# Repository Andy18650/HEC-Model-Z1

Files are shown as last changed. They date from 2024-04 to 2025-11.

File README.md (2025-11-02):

# HEC Model Z1
 A Z80 computer with protected mode support
This repository is currently for my own use and for the public to track the progress of the project. 
It is not meant to be used to produce a working computer befor first beta revision is announced.
Any part of this repository may change without notice.

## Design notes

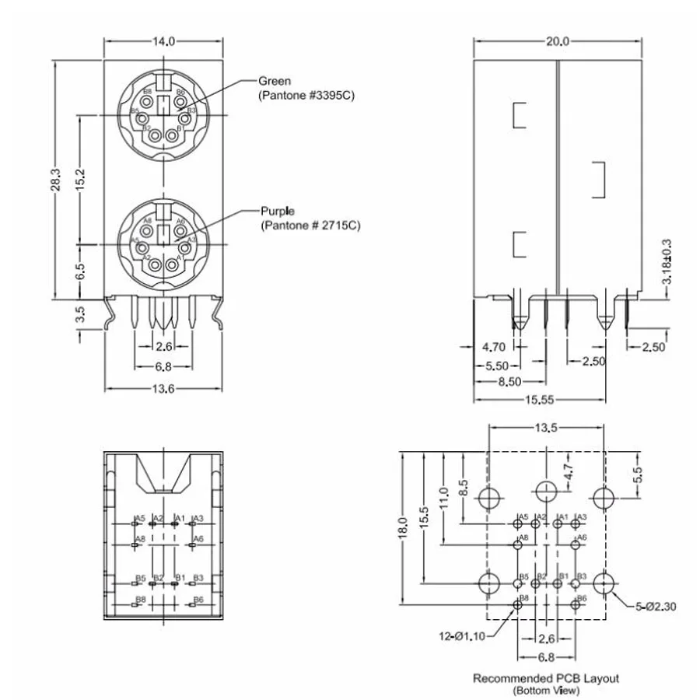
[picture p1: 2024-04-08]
mini-din-6x2.png

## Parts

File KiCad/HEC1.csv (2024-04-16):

Source: | C:\Users\11456\Desktop\Projects\HEC\HEC-Model-Z1\KiCad\HEC1.kicad_sch
Date: | 4/17/2024 1:12:58 AM
Tool: | Eeschema 7.0.2
Generator: | C:\Program Files\KiCad\7.0\bin\scripting\plugins/bom_csv_grouped_by_value.py
Component Count: | 119
Collated Components:
Item | Qty | Reference(s) | Value | LibPart | Footprint | Datasheet | DNP
1 | 1 | BUS1 | ~ | :Bus_HEC_1 | Library:Bus_HEC
2 | 1 | BUS2 | ~ | New_Library:Bus_HEC | Library:Bus_HEC
3 | 1 | BUS3 | ~ | :Bus_HEC_5Vonly_1 | Library:Bus_HEC_5Vonly
4 | 1 | BUS4 | ~ | New_Library:Bus_HEC_5Vonly | Library:Bus_HEC_5Vonly
5 | 24 | C1, C2, C3, C4, C5, C6, C7, C8, C13, C14, C15, C16, C17, C18, C19, C20, C22, C23, C24, C25, C26, C27, C28, C29 | C | Device:C | Capacitor_THT:C_Disc_D7.0mm_W2.5mm_P5.00mm | ~
6 | 3 | C9, C10, C11 | C_Polarized | Device:C_Polarized | Capacitor_THT:CP_Radial_D6.3mm_P2.50mm | ~
7 | 6 | C12, C21, C30, C33, C34, C35 | C_Polarized | Device:C_Polarized | Capacitor_THT:CP_Radial_D10.0mm_P5.00mm | ~
8 | 2 | C31, C32 | C | Device:C | Capacitor_THT:C_Disc_D3.4mm_W2.1mm_P2.50mm | ~
9 | 1 | D1 | LED | Device:LED | LED_THT:LED_D3.0mm | ~
10 | 6 | H1, H2, H3, H4, H5, H6 | MountingHole_Pad | Mechanical:MountingHole_Pad | MountingHole:MountingHole_3.2mm_M3_Pad_Via | ~
11 | 4 | H7, H8, H9, H10 | MountingHole | Mechanical:MountingHole | MountingHole:MountingHole_3.2mm_M3 | ~
12 | 1 | J1 | Barrel_Jack_Switch | Connector:Barrel_Jack_Switch | Connector_BarrelJack:BarrelJack_Kycon_KLDX-0202-xC_Horizontal | ~
13 | 1 | J2 | Conn_02x12_Odd_Even | Connector_Generic:Conn_02x12_Odd_Even | Connector_PinHeader_2.54mm:PinHeader_2x12_P2.54mm_Vertical | ~
14 | 1 | J3 | Conn_02x05_Odd_Even | Connector_Generic:Conn_02x05_Odd_Even | Connector_PinHeader_2.54mm:PinHeader_2x05_P2.54mm_Vertical | ~
15 | 1 | J4 | ~ | New_Library:double_mini-DIN_6 | Library:Connector_double_mini-DIN_6
16 | 1 | J5 | Screw_Terminal_01x02 | Connector:Screw_Terminal_01x02 | TerminalBlock_MetzConnect:TerminalBlock_MetzConnect_Type073_RT02602HBLU_1x02_P5.08mm_Horizontal | ~
17 | 1 | J6 | DE9_Plug_MountingHoles | Connector:DE9_Plug_MountingHoles | Connector_Dsub:DSUB-9_Male_Horizontal_P2.77x2.84mm_EdgePinOffset4.94mm_Housed_MountingHolesOffset7.48mm | ~
18 | 1 | J7 | AudioJack3 | Connector_Audio:AudioJack3 | Connector_Audio:Jack_3.5mm_CUI_SJ1-3533NG_Horizontal | ~
19 | 1 | J8 | NES_Port_Male | New_Library:NES_Port_Male | Library:NES_Port_Male_Horizontal
20 | 1 | J9 | Conn_02x14_Odd_Even | Connector_Generic:Conn_02x14_Odd_Even | Connector_PinHeader_2.54mm:PinHeader_2x14_P2.54mm_Vertical | ~
21 | 1 | PS1 | ITX0512S | Converter_DCDC:ITX0512S | Converter_DCDC:Converter_DCDC_XP_POWER-ITxxxxxS_THT | https://www.xppower.com/pdfs/SF_ITX.pdf
22 | 4 | R1, R2, R3, R4 | R | Device:R | Resistor_THT:R_Axial_DIN0207_L6.3mm_D2.5mm_P7.62mm_Horizontal | ~
23 | 2 | RN1, RN6 | R_Network08 | Device:R_Network08 | Resistor_THT:R_Array_SIP9 | http://www.vishay.com/docs/31509/csc.pdf
24 | 2 | RN2, RN7 | R_Network04 | Device:R_Network04 | Resistor_THT:R_Array_SIP5 | http://www.vishay.com/docs/31509/csc.pdf
25 | 2 | RN3, RN4 | R_Pack07 | Device:R_Pack07 | Package_DIP:DIP-14_W7.62mm | ~
26 | 1 | RN5 | R_Network07 | Device:R_Network07 | Resistor_THT:R_Array_SIP8 | http://www.vishay.com/docs/31509/csc.pdf
27 | 1 | SW1 | SW_DIP_x04 | Switch:SW_DIP_x04 | Button_Switch_THT:SW_DIP_SPSTx04_Slide_9.78x12.34mm_W7.62mm_P2.54mm | ~
28 | 1 | SW2 | SW_Push | Switch:SW_Push | Button_Switch_THT:SW_PUSH_6mm | ~
29 | 1 | U1 | Z80CPU | CPU:Z80CPU | Library:DIP-40_W15.24mm_Socket_ThinPads | www.zilog.com/manage_directlink.php?filepath=docs/z80/um0080
30 | 2 | U2, U3 | AS6C4008-55PCN | Memory_RAM:AS6C4008-55PCN | Library:DIP-32_W15.24mm_Socket_ThinPads | https://www.alliancememory.com/wp-content/uploads/pdf/AS6C4008.pdf
31 | 2 | U4, U5 | CY7C199 | Memory_RAM:CY7C199 | Library:DIP-28_W7.62mm_Socket_ThinPads
32 | 3 | U6, U8, U18 | 74LS138 | 74xx:74LS138 | Library:DIP-16_W7.62mm_Socket_ThinPads | http://www.ti.com/lit/gpn/sn74LS138
33 | 1 | U7 | 28C256 | Memory_EEPROM:28C256 | Library:DIP-28_W15.24mm_Socket_ThinPads | http://ww1.microchip.com/downloads/en/DeviceDoc/doc0006.pdf
34 | 4 | U9, U20, U21, U36 | 74LS574 | 74xx:74LS574 | Library:DIP-20_W7.62mm_Socket_ThinPads | http://www.ti.com/lit/gpn/sn74LS574
35 | 5 | U10, U15, U16, U31, U37 | 74LS32 | 74xx:74LS32 | Library:DIP-14_W7.62mm_Socket_ThinPads | http://www.ti.com/lit/gpn/sn74LS32
36 | 1 | U11 | 74LS00 | 74xx:74LS00 | Library:DIP-14_W7.62mm_Socket_ThinPads | http://www.ti.com/lit/gpn/sn74ls00
37 | 1 | U12 | 74LS04 | 74xx:74LS04 | Library:DIP-14_W7.62mm_Socket_ThinPads | http://www.ti.com/lit/gpn/sn74LS04
38 | 2 | U13, U14 | 74LS245 | 74xx:74LS245 | Library:DIP-20_W7.62mm_Socket_ThinPads | http://www.ti.com/lit/gpn/sn74LS245
39 | 2 | U17, U33 | 74LS20 | 74xx:74LS20 | Library:DIP-14_W7.62mm_Socket_ThinPads | http://www.ti.com/lit/gpn/sn74LS20
40 | 2 | U19, U28 | 74LS30 | 74xx:74LS30 | Library:DIP-14_W7.62mm_Socket_ThinPads | http://www.ti.com/lit/gpn/sn74LS30
41 | 2 | U22, U41 | 74LS02 | 74xx:74LS02 | Library:DIP-14_W7.62mm_Socket_ThinPads | http://www.ti.com/lit/gpn/sn74ls02
42 | 5 | U23, U24, U27, U29, U30 | 74LS74 | 74xx:74LS74 | Library:DIP-14_W7.62mm_Socket_ThinPads | 74xx/74hc_hct74.pdf
43 | 3 | U25, U26, U44 | 74LS541 | 74xx:74LS541 | Library:DIP-20_W7.62mm_Socket_ThinPads | http://www.ti.com/lit/gpn/sn74LS541
44 | 1 | U32 | LM79M05_TO220 | Regulator_Linear:LM79M05_TO220 | Package_TO_SOT_THT:TO-220-3_Vertical | https://www.onsemi.com/pub/Collateral/MC79M00-D.PDF
45 | 1 | U34 | 74LS393 | 74xx:74LS393 | Library:DIP-14_W7.62mm_Socket_ThinPads | 74xx\74LS393.pdf
46 | 1 | U35 | 74LS08 | 74xx:74LS08 | Library:DIP-14_W7.62mm_Socket_ThinPads | http://www.ti.com/lit/gpn/sn74LS08
47 | 2 | U38, U39 | 74LS47 | 74xx:74LS47 | Library:DIP-16_W7.62mm_Socket_ThinPads | http://www.ti.com/lit/gpn/sn74LS47
48 | 1 | U40 | DA04-11EWA | Display_Character:DA04-11EWA | Display_7Segment:DA04-11SURKWA | http://www.kingbrightusa.com/images/catalog/SPEC/DA04-11EWA.pdf
49 | 1 | U42 | 74LS06 | 74xx:74LS06 | Library:DIP-14_W7.62mm_Socket_ThinPads | http://www.ti.com/lit/gpn/sn74LS06
50 | 1 | U43 | ~ | New_Library:HT6542B | Library:DIP-40_W15.24mm_Socket_ThinPads
51 | 1 | X1 | CXO_DIP8 | Oscillator:CXO_DIP8 | Oscillator:Oscillator_DIP-8 | http://cdn-reichelt.de/documents/datenblatt/B400/OSZI.pdf
52 | 1 | Y1 | Crystal | Device:Crystal | Crystal:Crystal_HC18-U_Vertical | ~

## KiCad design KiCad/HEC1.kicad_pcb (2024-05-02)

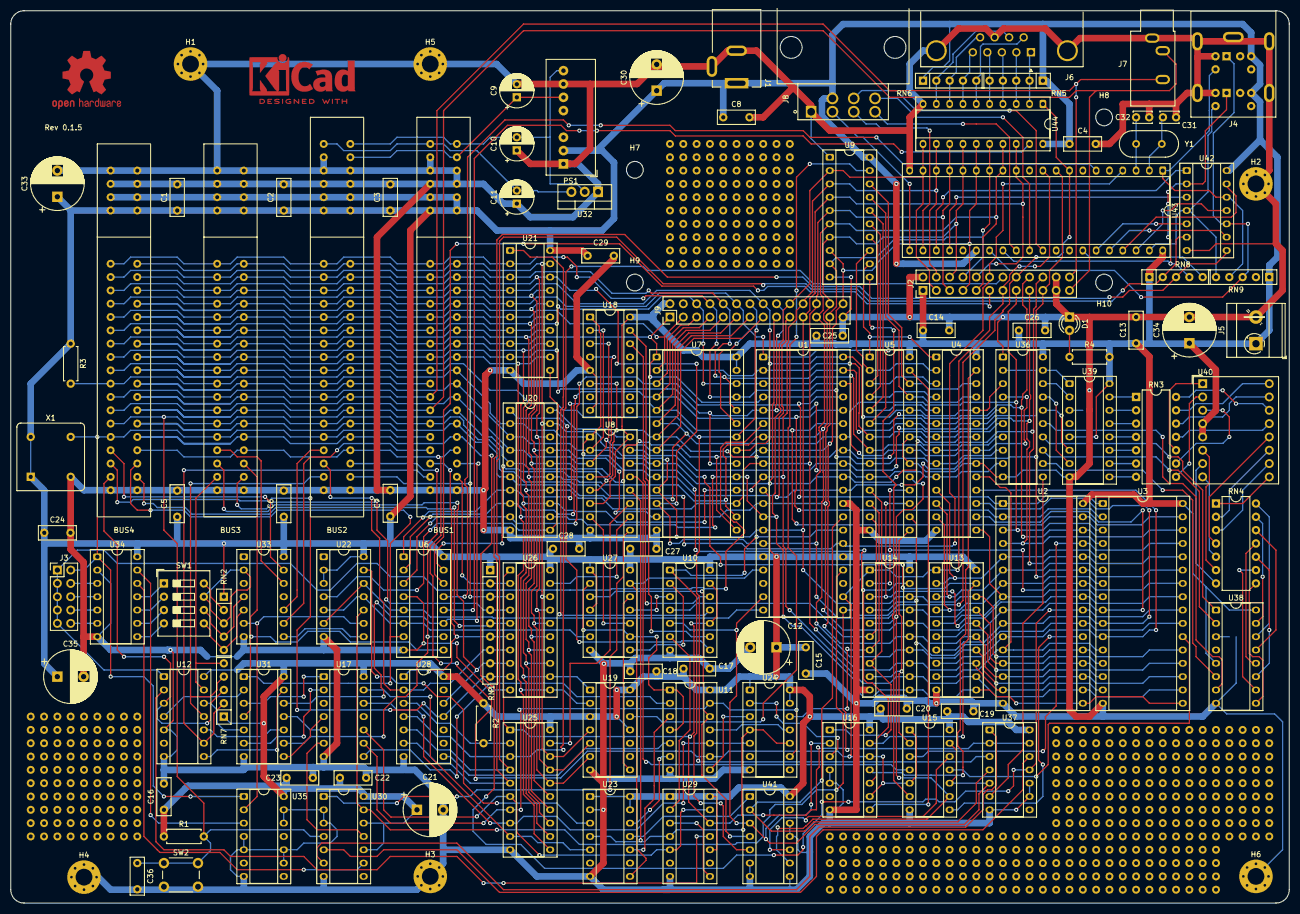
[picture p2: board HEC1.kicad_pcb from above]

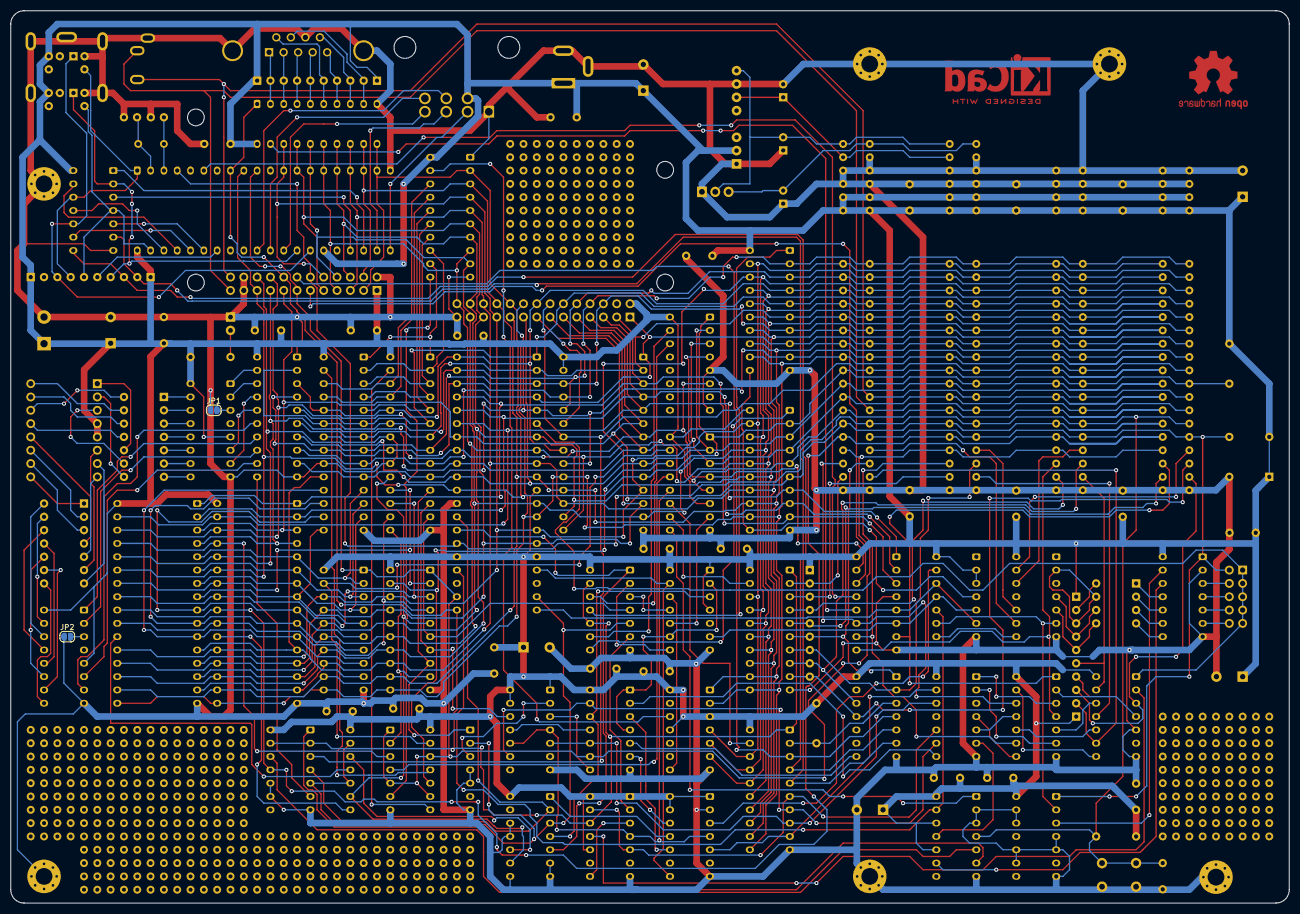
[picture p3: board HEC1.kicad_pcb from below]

Board: 2 copper layers, 243.8 x 170.2 mm, 124 parts (2 on the bottom side), 232 nets.

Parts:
BUS1, BUS2: Bus_HEC
BUS3, BUS4: Bus_HEC_5Vonly
C1, C2, C3, C4, C5, C6, C7, C8, C13, C14, C15, C16, C17, C18, C19, C20, C22, C23, C24, C25, C26, C27, C28, C29, C36: C; C_Disc_D7.0mm_W2.5mm_P5.00mm
C9, C10, C11: C_Polarized; CP_Radial_D6.3mm_P2.50mm
C12, C21, C30, C33, C34, C35: C_Polarized; CP_Radial_D10.0mm_P5.00mm
C31, C32: C; C_Disc_D3.4mm_W2.1mm_P2.50mm
D1: LED; LED_D3.0mm
H1, H2, H3, H4, H5, H6: MountingHole_Pad; MountingHole_3.2mm_M3_Pad_Via
H7, H8, H9, H10: MountingHole; MountingHole_3.2mm_M3
J1: Barrel_Jack_Switch; BarrelJack_Kycon_KLDX-0202-xC_Horizontal
J2: Conn_02x12_Odd_Even; PinHeader_2x12_P2.54mm_Vertical
J3: Conn_02x05_Odd_Even; PinHeader_2x05_P2.54mm_Vertical
J4: Connector_double_mini-DIN_6
J5: Screw_Terminal_01x02; TerminalBlock_MetzConnect_Type073_RT02602HBLU_1x02_P5.08mm_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
J6: DE9_Plug_MountingHoles; DSUB-9_Male_Horizontal_P2.77x2.84mm_EdgePinOffset4.94mm_Hou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
J7: AudioJack3; Jack_3.5mm_CUI_SJ1-3533NG_Horizontal
J8: NES_Port_Male; NES_Port_Male_Horizontal
J9: Conn_02x14_Odd_Even; PinHeader_2x14_P2.54mm_Vertical
JP1, JP2: SolderJumper_2_Open; SolderJumper-2_P1.3mm_Open_RoundedPad1.0x1.5mm
PS1: ITX0512S; Converter_DCDC_XP_POWER-ITxxxxxS_THT
R1, R2, R3, R4: R; R_Axial_DIN0207_L6.3mm_D2.5mm_P7.62mm_Horizontal
RN1: R_Network08; R_Array_SIP9
RN2, RN5, RN6, RN7, RN8, RN9: R_Network04; R_Array_SIP5
RN3, RN4: R_Pack07; DIP-14_W7.62mm
SW1: SW_DIP_x04; SW_DIP_SPSTx04_Slide_9.78x12.34mm_W7.62mm_P2.54mm
SW2: SW_Push; SW_PUSH_6mm
U1: Z80CPU; DIP-40_W15.24mm_Socket_ThinPads
U2, U3: AS6C4008-55PCN; DIP-32_W15.24mm_Socket_ThinPads
U4, U5: CY7C199; DIP-28_W7.62mm_Socket_ThinPads
U6, U8, U18: 74LS138; DIP-16_W7.62mm_Socket_ThinPads
U7: 28C256; DIP-28_W15.24mm_Socket_ThinPads
U9, U20, U21, U36: 74LS574; DIP-20_W7.62mm_Socket_ThinPads
U10, U15, U16, U31, U37: 74LS32; DIP-14_W7.62mm_Socket_ThinPads
U11: 74LS00; DIP-14_W7.62mm_Socket_ThinPads
U12: 74LS04; DIP-14_W7.62mm_Socket_ThinPads
U13, U14: 74LS245; DIP-20_W7.62mm_Socket_ThinPads
U17, U33: 74LS20; DIP-14_W7.62mm_Socket_ThinPads
U19, U28: 74LS30; DIP-14_W7.62mm_Socket_ThinPads
U22, U41: 74LS02; DIP-14_W7.62mm_Socket_ThinPads
U23, U24, U27, U29, U30: 74LS74; DIP-14_W7.62mm_Socket_ThinPads
U25, U26, U44: 74LS541; DIP-20_W7.62mm_Socket_ThinPads
U32: LM79M05_TO220; TO-220-3_Vertical
U34: 74LS393; DIP-14_W7.62mm_Socket_ThinPads
U35: 74LS08; DIP-14_W7.62mm_Socket_ThinPads
U38, U39: 74LS47; DIP-16_W7.62mm_Socket_ThinPads
U40: DA04-11EWA; DA04-11SURKWA
U42: 74LS06; DIP-14_W7.62mm_Socket_ThinPads
U43: DIP-40_W15.24mm_Socket_ThinPads
X1: CXO_DIP8; Oscillator_DIP-8
Y1: Crystal; Crystal_HC18-U_Vertical

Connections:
/HEC_CPU/CLK: J3.1, J3.3, J3.5, J3.7, J3.9, U1.6 (~CLK), U12.1
/HEC_CPU/~IOPORT_H: U10.12, U18.14 (O1)
/HEC_CPU/~IOPORT_L: U10.9, U18.15 (O0)
/HEC_CPU/~IORQ: U1.20 (~IORQ), U6.5 (E2), U22.6, U22.12
/HEC_CPU/~MREQ: U1.19 (~MREQ), U10.5, U15.10, U15.13, U16.2, U37.5, U41.3
/HEC_CPU/~NMI: U1.17 (~NMI), U23.8 (~Q), U27.13 (~R)
/HEC_CPU/~RAMEN: U8.9 (O6), U30.1 (~R)
/HEC_CPU/~RD: J2.16, U1.21 (~RD), U10.10, U10.13, U25.1 (G1), U26.1 (G1), U29.12 (D), U37.2, U37.13, U43.8 (~RD), U44.1 (G1)
/HEC_CPU/~RESET: BUS1.25 (~RESET), BUS2.25 (~RESET), BUS3.25 (~RESET), BUS4.25 (~RESET), C36.1, J2.12, R1.2, SW2.1, U1.26 (~RESET), U30.4 (~S), U43.4 (~RESET)
/HEC_CPU/~RFSH: U1.28 (~RFSH), U37.4, U41.2
/HEC_CPU/~WAIT: U1.24 (~WAIT), U22.10, U30.13 (~R)
/HEC_CPU/~WR: BUS1.30 (~IOW), BUS2.30 (~IOW), BUS3.30 (~IOW), BUS4.30 (~IOW), J2.13, U1.22 (~WR), U11.9, U13.1 (A->B), U14.1 (A->B), U15.1, U15.5, U16.9, U16.12, U43.10 (~WR)
/HEC_IO/+12V: BUS1.P4 (+12V), BUS2.P4 (+12V), C9.1, PS1.6 (+Vout)
/HEC_IO/-5V: BUS1.P1 (-5V), BUS2.P1 (-5V), C11.2, U32.3 (VO)
/HEC_IO/-12V: BUS1.P2 (-12V), BUS2.P2 (-12V), C10.2, PS1.8 (-Vout), U32.2 (VI)
/HEC_IO/A0: BUS1.18 (PA0), BUS2.18 (PA0), BUS3.18 (PA0), BUS4.18 (PA0), J2.19, J9.19, U1.30 (A0), U2.27 (A8), U3.27 (A8), U7.10 (A0), U8.1 (A0), U18.1 (A0), U20.2 (D0), U43.9 (A0)
/HEC_IO/A1: BUS1.20 (PA1), BUS2.20 (PA1), BUS3.20 (PA1), BUS4.20 (PA1), J2.20, J9.17, U1.31 (A1), U2.28 (A13), U3.28 (A13), U7.9 (A1), U8.2 (A1), U18.2 (A1), U20.3 (D1)
/HEC_IO/A2: BUS1.22 (PA2), BUS2.22 (PA2), BUS3.22 (PA2), BUS4.22 (PA2), J2.17, J9.15, U1.32 (A2), U2.4 (A12), U3.4 (A12), U7.8 (A2), U8.3 (A2), U18.3 (A2), U20.4 (D2)
/HEC_IO/A3: BUS1.24 (PA3), BUS2.24 (PA3), BUS3.24 (PA3), BUS4.24 (PA3), J2.18, J9.13, U1.33 (A3), U2.30 (A17), U3.30 (A17), U7.7 (A3), U8.5 (E2), U18.6 (E3), U20.5 (D3)
/HEC_IO/A4: BUS1.26 (PA4), BUS2.26 (PA4), BUS3.26 (PA4), BUS4.26 (PA4), J2.15, J9.11, U1.34 (A4), U2.3 (A14), U3.3 (A14), U7.6 (A4), U20.6 (D4)
/HEC_IO/A5: J9.9, U1.35 (A5), U2.31 (A15), U3.31 (A15), U6.1 (A0), U7.5 (A5), U20.7 (D5)
/HEC_IO/A6: J9.7, U1.36 (A6), U2.2 (A16), U3.2 (A16), U6.2 (A1), U7.4 (A6), U20.8 (D6)
/HEC_IO/A7: J9.5, U1.37 (A7), U2.1 (A18), U3.1 (A18), U6.3 (A2), U7.3 (A7), U20.9 (D7)
/HEC_IO/A8: BUS1.1 (A0), BUS2.1 (A0), BUS3.1 (A0), BUS4.1 (A0), J9.8, U1.38 (A8), U4.21 (A0), U5.21 (A0), U7.25 (A8), U21.2 (D0), U36.4 (D2)
/HEC_IO/A9: BUS1.3 (A1), BUS2.3 (A1), BUS3.3 (A1), BUS4.3 (A1), J9.10, U1.39 (A9), U4.23 (A1), U5.23 (A1), U7.24 (A9), U21.3 (D1), U36.2 (D0)
/HEC_IO/A10: BUS1.5 (A2), BUS2.5 (A2), BUS3.5 (A2), BUS4.5 (A2), J9.16, U1.40 (A10), U4.24 (A2), U5.24 (A2), U7.21 (A10), U21.4 (D2), U36.3 (D1)
/HEC_IO/A11: BUS1.7 (A3), BUS2.7 (A3), BUS3.7 (A3), BUS4.7 (A3), J9.12, U1.1 (A11), U4.6 (A10), U5.6 (A10), U7.23 (A11), U21.5 (D3), U36.5 (D3)
/HEC_IO/A12: BUS1.9 (A4), BUS2.9 (A4), BUS3.9 (A4), BUS4.9 (A4), J9.3, U1.2 (A12), U4.7 (A11), U5.7 (A11), U7.2 (A12), U21.6 (D4), U36.6 (D4)
/HEC_IO/A13: BUS1.11 (A5), BUS2.11 (A5), BUS3.11 (A5), BUS4.11 (A5), J9.6, U1.3 (A13), U4.8 (A12), U5.8 (A12), U7.26 (A13), U21.7 (D5), U36.7 (D5)
/HEC_IO/A14: BUS1.13 (A6), BUS2.13 (A6), BUS3.13 (A6), BUS4.13 (A6), J9.1, U1.4 (A14), U4.9 (A13), U5.9 (A13), U7.1 (A14), U21.8 (D6), U36.8 (D6)
/HEC_IO/A15: BUS1.15 (A7), BUS2.15 (A7), BUS3.15 (A7), BUS4.15 (A7), J9.18, U1.5 (A15), U4.10 (A14), U5.10 (A14), U7.20 (~CS), U21.9 (D7), U36.9 (D7)
/HEC_IO/AUDIO_L: BUS1.21 (AUDIO_L), BUS2.21 (AUDIO_L), BUS3.21 (AUDIO_L), BUS4.21 (AUDIO_L), J2.24, J7.R
/HEC_IO/AUDIO_R: BUS1.23 (AUDIO_R), BUS2.23 (AUDIO_R), BUS3.23 (AUDIO_R), BUS4.23 (AUDIO_R), J2.23, J7.T
/HEC_IO/D0: BUS1.2 (D0), BUS2.2 (D0), BUS3.2 (D0), BUS4.2 (D0), J2.10, J9.21, U1.14 (D0), U2.21 (DQ7), U3.21 (DQ7), U7.11 (D0), U9.4 (D2), U13.18 (B0), U14.18 (B0), U19.4, U20.19 (Q0), U21.19 (Q0), U25.18 (Y0), U26.18 (Y0), U43.12 (D0), U44.18 (Y0)
/HEC_IO/D1: BUS1.4 (D1), BUS2.4 (D1), BUS3.4 (D1), BUS4.4 (D1), J2.9, J9.23, U1.15 (D1), U2.13 (DQ0), U3.13 (DQ0), U7.12 (D1), U9.6 (D4), U13.17 (B1), U14.17 (B1), U19.5, U20.18 (Q1), U21.18 (Q1), U25.17 (Y1), U26.17 (Y1), U43.13 (D1), U44.17 (Y1)
/HEC_IO/D2: BUS1.6 (D2), BUS2.6 (D2), BUS3.6 (D2), BUS4.6 (D2), J2.8, J9.25, U1.12 (D2), U2.20 (DQ6), U3.20 (DQ6), U7.13 (D2), U9.9 (D7), U13.16 (B2), U14.16 (B2), U19.6, U20.17 (Q2), U21.17 (Q2), U25.16 (Y2), U26.16 (Y2), U43.14 (D2), U44.16 (Y2)
/HEC_IO/D3: BUS1.8 (D3), BUS2.8 (D3), BUS3.8 (D3), BUS4.8 (D3), J2.7, J9.28, U1.8 (D3), U2.14 (DQ1), U3.14 (DQ1), U7.15 (D3), U9.8 (D6), U13.15 (B3), U14.15 (B3), U20.16 (Q3), U21.16 (Q3), U25.15 (Y3), U26.15 (Y3), U43.15 (D3), U44.15 (Y3)
/HEC_IO/D4: BUS1.10 (D4), BUS2.10 (D4), BUS3.10 (D4), BUS4.10 (D4), J2.6, J9.26, U1.7 (D4), U2.19 (DQ5), U3.19 (DQ5), U7.16 (D4), U9.7 (D5), U13.14 (B4), U14.14 (B4), U20.15 (Q4), U21.15 (Q4), U25.14 (Y4), U26.14 (Y4), U43.16 (D4), U44.14 (Y4)
/HEC_IO/D5: BUS1.12 (D5), BUS2.12 (D5), BUS3.12 (D5), BUS4.12 (D5), J2.5, J9.24, U1.9 (D5), U2.15 (DQ2), U3.15 (DQ2), U7.17 (D5), U9.5 (D3), U13.13 (B5), U14.13 (B5), U20.14 (Q5), U21.14 (Q5), U25.13 (Y5), U26.13 (Y5), U43.17 (D5), U44.13 (Y5)
/HEC_IO/D6: BUS1.14 (D6), BUS2.14 (D6), BUS3.14 (D6), BUS4.14 (D6), J2.4, J9.22, U1.10 (D6), U2.18 (DQ4), U3.18 (DQ4), U7.18 (D6), U9.3 (D1), U13.12 (B6), U14.12 (B6), U19.1, U20.13 (Q6), U21.13 (Q6), U25.12 (Y6), U26.12 (Y6), U43.18 (D6), U44.12 (Y6)
/HEC_IO/D7: BUS1.16 (D7), BUS2.16 (D7), BUS3.16 (D7), BUS4.16 (D7), J2.3, J9.20, U1.13 (D7), U2.17 (DQ3), U3.17 (DQ3), U7.19 (D7), U9.2 (D0), U13.11 (B7), U14.11 (B7), U19.2, U20.12 (Q7), U21.12 (Q7), U25.11 (Y7), U26.11 (Y7), U43.19 (D7), U44.11 (Y7)
/HEC_IO/OSC: BUS1.27 (OSC), BUS2.27 (OSC), BUS3.27 (OSC), BUS4.27 (OSC), J3.2, U34.1 (CP), U35.1, X1.5 (OUT)
/HEC_IO/~IOR: BUS1.28 (~IOR), BUS2.28 (~IOR), BUS3.28 (~IOR), BUS4.28 (~IOR), U2.24 (OE#), U3.24 (OE#), U37.11
/HEC_IO/~IO_CS0: U6.15 (O0), U8.4 (E1), U18.4 (E1)
/HEC_IO/~IO_CS1: J2.11, U6.14 (O1)
/HEC_IO/~IO_CS2: U6.13 (O2), U43.6 (~CS)
/HEC_IO/~IO_CS3: U6.12 (O3), U44.19 (G2)
/HEC_IO/~IO_CS4: BUS1.32 (~IOCS), U6.11 (O4), U31.12
/HEC_IO/~IO_CS5: BUS2.32 (~IOCS), U6.10 (O5), U31.9
/HEC_IO/~IO_CS6: BUS3.32 (~IOCS), U6.9 (O6), U31.4
/HEC_IO/~IO_CS7: BUS4.32 (~IOCS), U6.7 (O7), U31.1
/HEC_IO/~IRQ1: BUS1.31 (~IRQ), RN1.6 (R5), U26.6 (A4), U28.1
/HEC_IO/~IRQ2: BUS2.31 (~IRQ), RN1.7 (R6), U26.7 (A5), U28.2
/HEC_IO/~IRQ3: BUS3.31 (~IRQ), RN1.8 (R7), U26.8 (A6), U28.12
/HEC_IO/~IRQ4: BUS4.31 (~IRQ), RN1.9 (R8), U26.9 (A7), U28.11
/HEC_IO/~NOWS1: BUS1.33 (~NOWS), RN7.2 (R1), U12.9
/HEC_IO/~NOWS2: BUS2.33 (~NOWS), RN7.4 (R3), U12.11
/HEC_IO/~NOWS3: BUS3.33 (~NOWS), RN7.5 (R4), U12.13
/HEC_IO/~NOWS4: BUS4.33 (~NOWS), RN7.3 (R2), U12.3
/HEC_IO/~ROM_OE: BUS1.17 (~ROMR), BUS2.17 (~ROMR), BUS3.17 (~ROMR), BUS4.17 (~ROMR), J9.14, U7.22 (~OE), U37.3
/HEC_IO/~ROM_WE: BUS1.19 (~ROMW), BUS2.19 (~ROMW), BUS3.19 (~ROMW), BUS4.19 (~ROMW), R3.2
/HEC_IO/~SENSE1: BUS1.34 (~SENSE), RN1.2 (R1), U26.2 (A0)
/HEC_IO/~SENSE2: BUS2.34 (~SENSE), RN1.3 (R2), U26.3 (A1)
/HEC_IO/~SENSE3: BUS3.34 (~SENSE), RN1.4 (R3), U26.4 (A2)
/HEC_IO/~SENSE4: BUS4.34 (~SENSE), RN1.5 (R4), U26.5 (A3)
/HEC_IO/~WAIT1: BUS1.29 (~WAIT), U33.9
/HEC_IO/~WAIT2: BUS2.29 (~WAIT), U33.10
/HEC_IO/~WAIT3: BUS3.29 (~WAIT), U33.12
/HEC_IO/~WAIT4: BUS4.29 (~WAIT), U33.13
/HEC_Memory/ATTR_NX: U5.12 (D1), U14.7 (A5), U24.12 (D)
/HEC_Memory/ATTR_RI: U5.13 (D2), U10.4, U14.6 (A4)
/HEC_Memory/ATTR_WI: U5.11 (D0), U14.8 (A6), U16.1
/HEC_Memory/ATTR_WP: U5.15 (D3), U14.9 (A7), U15.2
/HEC_Memory/PROC_ID0: U4.25 (A3), U5.25 (A3), U9.17 (Q2)
/HEC_Memory/PROC_ID1: U4.4 (A8), U5.4 (A8), U9.15 (Q4)
/HEC_Memory/PROC_ID2: U4.1 (A5), U5.1 (A5), U9.12 (Q7)
/HEC_Memory/PROC_ID3: U4.2 (A6), U5.2 (A6), U9.13 (Q6)
/HEC_Memory/PROC_ID4: U4.3 (A7), U5.3 (A7), U9.14 (Q5)
/HEC_Memory/PROC_ID5: U4.5 (A9), U5.5 (A9), U9.16 (Q3)
/HEC_Memory/PROC_ID6: U4.26 (A4), U5.26 (A4), U9.18 (Q1)
/HEC_Memory/RAM_A8: U2.5 (A7), U3.5 (A7), U4.11 (D0), U13.2 (A0)
/HEC_Memory/RAM_A9: U2.6 (A6), U3.6 (A6), U4.12 (D1), U13.3 (A1)
/HEC_Memory/RAM_A10: U2.7 (A5), U3.7 (A5), U4.13 (D2), U13.4 (A2)
/HEC_Memory/RAM_A11: U2.8 (A4), U3.8 (A4), U4.15 (D3), U13.5 (A3)
/HEC_Memory/RAM_A12: U2.9 (A3), U3.9 (A3), U4.16 (D4), U13.6 (A4)
/HEC_Memory/RAM_A13: U2.10 (A2), U3.10 (A2), U4.17 (D5), U13.7 (A5)
/HEC_Memory/RAM_A14: U2.11 (A1), U3.11 (A1), U4.18 (D6), U13.8 (A6)
/HEC_Memory/RAM_A15: U2.12 (A0), U3.12 (A0), U4.19 (D7), U13.9 (A7)
/HEC_Memory/RAM_A16: U2.26 (A9), U3.26 (A9), U5.18 (D6), U14.2 (A0)
/HEC_Memory/RAM_A17: U2.25 (A11), U3.25 (A11), U5.17 (D5), U14.3 (A1)
/HEC_Memory/RAM_A18: U2.23 (A10), U3.23 (A10), U5.16 (D4), U14.4 (A2)
/HEC_Memory/RAM_A19: U5.19 (D7), U14.5 (A3), U15.9, U41.9
/HEC_Memory/SYSGATE: U9.19 (Q0), U19.12
/HEC_Memory/~PAGE_H_WE: U5.27 (~WE), U16.8
/HEC_Memory/~PAGE_H: U8.14 (O1), U14.19 (CE), U16.10
/HEC_Memory/~PAGE_L_WE: U4.27 (~WE), U16.11
/HEC_Memory/~PAGE_L: U8.15 (O0), U13.19 (CE), U16.13
/HEC_Memory/~PID: U8.13 (O2), U15.4
/HEC_Memory/~RAM0CS: U2.22 (CE#), U15.8
/HEC_Memory/~RAM1CS: U3.22 (CE#), U15.11
/HEC_Memory/~RAM_A19: U15.12, U41.10
/HEC_Memory/~RAM_WR: U2.29 (WE#), U3.29 (WE#), U15.3
/HEC_Peripherals/~KB_IRQ: RN8.2 (R1), U25.4 (A2), U28.5, U42.6
/HEC_Peripherals/~MS_IRQ: RN8.3 (R2), U25.5 (A3), U28.6, U42.8
/HEC_Protection/M1: U11.12, U27.3 (C), U41.4
/HEC_Protection/SYS: U6.6 (E3), U22.5, U22.11, U27.6 (~Q)
/HEC_Protection/~AUX_IRQ: R2.2, U25.2 (A0), U28.3
/HEC_Protection/~CLRINT: U8.12 (O3), U23.4 (~S), U24.4 (~S), U24.10 (~S), U29.4 (~S)
/HEC_Protection/~GOUSR: U8.7 (O7), U27.10 (~S)
/HEC_Protection/~INT_SOURCE_1: U8.11 (O4), U25.19 (G2)
/HEC_Protection/~INT_SOURCE_2: U8.10 (O5), U26.19 (G2)
/HEC_Protection/~IO_PROT: U17.13, U23.5 (Q), U25.9 (A7)
/HEC_Protection/~M1: U1.27 (~M1), U10.1, U41.5
/HEC_Protection/~RFAULT: U17.10, U25.6 (A4), U29.5 (Q), U29.13 (~R)
/HEC_Protection/~VDP_IRQ: J2.14, U25.3 (A1), U28.4
/HEC_Protection/~WFAULT: U11.10, U17.12, U24.5 (Q), U25.8 (A6)
/HEC_Protection/~XFAULT: U11.13, U17.9, U24.9 (Q), U25.7 (A5)
H: BUS1.P9 (+5V), BUS1.P10 (+5V), BUS1.P11 (+5V), BUS1.P12 (+5V), BUS2.P9 (+5V), BUS2.P10 (+5V), BUS2.P11 (+5V), BUS2.P12 (+5V), BUS3.P9 (+5V), BUS3.P10 (+5V), BUS3.P11 (+5V), BUS3.P12 (+5V), BUS4.P9 (+5V), BUS4.P10 (+5V), BUS4.P11 (+5V), BUS4.P12 (+5V), C1.1, C2.1, C3.1, C4.1, C5.1, C6.1, C7.1, C8.1, C12.1, C13.1, C14.1, C15.1, C16.1, C17.1, C18.1, C19.1, C20.1, C21.1, C22.1, C23.1, C24.1, C25.1, C26.1, C27.1, C28.1, C29.1, C30.1, C33.1, C34.1, C35.1, J1.1, J2.1, J4.A4, J4.B4, J5.1, J8.7 (VDD), J9.2, PS1.2 (+Vin), R1.1, R2.1, R3.1, R4.2, RN1.1 (common), RN2.1 (common), RN5.1 (common), RN6.1 (common), RN7.1 (common), RN8.1 (common), RN9.1 (common), U1.11 (VCC), U1.16 (~INT), U1.25 (~BUSRQ), U2.32 (VCC), U3.32 (VCC), U4.28 (VCC), U5.28 (VCC), U6.16 (VCC), U7.27 (~WE), U7.28 (VCC), U8.6 (E3), U8.16 (VCC), U9.20 (VCC), U10.14 (VCC), U11.14 (VCC), U12.14 (VCC), U13.20 (VCC), U14.20 (VCC), U15.14 (VCC), U16.14 (VCC), U17.14 (VCC), U18.16 (VCC), U19.3, U19.11, U19.14 (VCC), U20.20 (VCC), U21.20 (VCC), U22.2, U22.3, U22.14 (VCC), U23.1 (~R), U23.13 (~R), U23.14 (VCC), U24.1 (~R), U24.13 (~R), U24.14 (VCC), U25.20 (VCC), U26.20 (VCC), U27.1 (~R), U27.4 (~S), U27.14 (VCC), U28.14 (VCC), U29.1 (~R), U29.10 (~S), U29.14 (VCC), U30.10 (~S), U30.12 (D), U30.14 (VCC), U31.14 (VCC), U33.14 (VCC), U34.14 (VCC), U35.14 (VCC), U36.20 (VCC), U37.14 (VCC), U38.5 (RBI), U38.16 (VCC), U39.5 (RBI), U39.16 (VCC), U40.4 (DIG1_CA), U40.5 (DIG2_CA), U41.14 (VCC), U42.14 (VCC), U43.26 (TEST), U43.40 (VCC), U44.20 (VCC), X1.1 (EN), X1.8 (Vcc)
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

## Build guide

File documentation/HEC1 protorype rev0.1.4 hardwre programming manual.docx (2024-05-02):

HEC Model Z1 Rev 0.1.4Hardware Programming Manual

# Pages

A page is a continuous region of memory. Each page is 256 bytes long. A total of 256 pages can exist in a single address space. Up to 128 independent address spaces are supported by the paging hardware. These pages are selected from 4096 pages or 1MiB of memory.

Two different pages within the address space can point to the same page on physical memory. In such case, and any operations performed on one page will be mirrored to the other page, since they are physically the same page.

Each page can be marked as Write-Protected (WP), Write-Interrupt (WI), Read-Interrupt (RI) and No-Opcode-Fetch (NX). Writes to a Write-Protected page is discarded and has no effect. The effects of other bits will be discussed in detail in the ‘Operating Modes’ section.

All pages contain RAM only, no MMIO is used in HEC, and no ROM is mapped to RAM space. ROM can be emulated by setting a page of RAM to write-protected. RAM is always mapped by the paging circuit. There is no way to turn off RAM mapping. A flat memory model can be emulated by setting each page entry in one address space to a different physical page.

# Operating Modes

## 2.1 USR mode

Code running in user (USR) mode cannot perform IO operations. Running any IO instruction in user mode would have no effect and immediately trigger an NMI. NMI will also be triggered if the code tries to write to a Write-Interrupt page, or read from a Read-Interrupt page, or fetch an opcode from a No-Opcode-Fetch page. (caution: the Z80 is only consider the first cycle of an instruction an opcode fetch cycle, or M1 cycle. Therefore, later bytes in the instruction, such as address or immediate number, will not be considered as opcodes and will not trigger an NMI if read from a No-Opcode-Fetch page). A write to a write-protected will not generate an NMI unless the same page has been set to write-interrupt. External Interrupt can occur in USR mode as NMI.

User mode can be entered from system mode via either a read or a write access to the GOUSR port (port address: 0x07).

## 2.2 SYS mode

Code running in system (SYS) mode can perform IO operations to access peripherals. Details of such operations will be discussed in detail in ‘Input and Output’ section.

All interrupts, internal or external, are masked in system mode. However, interrupts are still generated by the hardware. One case that should be paid special attention is the page attributes: interrupts will be generated as if the code is running in user mode. So, if page attribute bits are used to control access to the page (for example, using RI bit to prevent user programs from accessing sensitive information), system routines must clear internal interrupts after accessing those pages. This can be accomplished by either a read or a write to the CLRINT port (port address: 0x03).

System mode is entered via wither an RST instruction, or an NMI. Note that the HEC is not guaranteed to be in system mode immediately after reset. It is necessary that the programmer explicitly put the HEC into system mode during the POST process.

## 2.3 ROM mode

The HEC is put into ROM mode immediately after a reset. In ROM mode, the lower half of the address space is 32KiB of onboard boot ROM, and the upper half is empty. Technically ROM mode and USR/SYS modes are completely orthogonal, however, there is little to no point in putting the HEC into user mode before exiting ROM mode.

The onboard ROM is not mapped by the paging circuit and cannot be written to. Any write in ROM mode will be directed to RAM and is subject to RAM mapping and attribute bits. Therefore, it is necessary to initialize the paging circuit before writing to RAM.

In ROM mode, all read access to external IO devices (expansion cards) will be redirected to ROM read. The high byte of the address bus is used as lower address byte to ROM, and 5 IO port bits are used as higher address bits of ROM. This setup facilitates the use of a INDR instruction to quickly copy ROM on a card into RAM.

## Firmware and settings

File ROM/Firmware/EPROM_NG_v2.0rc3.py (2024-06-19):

# kris@mygeekyhobby.com
#
# ver 1.0 - may 2020	- initial release
# ver 1.2 - june 2020 	- added save to SPI EEPROM functionality
# 						- fixed the args parsing
#						- added auto load wait option
#						- added save SPI option
# ver 1.3 - july 2020	- removed some of the debug stuff
#						- removed address scrolling when loading
# ver 1.6g - Aug 2020	- Lunches GUI when no parameters specified (code contributed by John Gerrard)... requires PySimpleGUI module "pip install PySimpleGUI"
#						- small fixes to the output
# ver 1.6e              - fixed bug with SPI==y 
#
# ver 2.0rc1 - Oct 2020   	- save parameters in GUI
#							- .bin and .hex file support
#							- binary mode upload with packets of 128-512 bytes at a time
#							- Save to SPI works with any type of data range (any source file less than 128 bytes gets "padded" with 0xFF)
# ver 2.0rc2 - Oct 2020   	- support other extenstions like .rom .img etc... everything not .hex is treated as binary (thanks to Hubert for the feedback and contribution)
#                           - fixed bug where a 128Byte of "00h" was treated as "no data" (thanks to Hubert for the feedback and contribution)
# ver 2.0rc3 - Oct 2020     - code from rc1 that was missing in rc2 was added back, one typo fixed (thx again Hubert)   	

version = "2.0rc3"

import argparse
import serial,os
import time
#import PySimpleGUI as sg
import sys

# All routines here

# Print int list in Hex format (for debugging only)
def PrintHex(intList):
	row = 0
	for val in intList:
		print("%0.2X"%val, end=' ', flush=True)
		row += 1
		if row == 64:
			print("")
			row=0
# -----------------------------------------------------------------------
def chunkData(bfr):
	"""
	Analyze the 64k buffer, find all 128Byte chunks that are in use (have data != to -1)
	Will return a list of 512 entries with "1" meaning block of 128Bytes had data chaned and "0" no data changed
	"""
	mapped=[]

	for i in range(0,len(bfr),128):
		chunk = bfr[i:i+128]		# split buffer into 128 Bytes chunks
		
		used = False

		for cell in chunk:				# if any byte changed, mark chunk for upload
			if cell >= 0:
				used = True
		
		if used:
			mapped.append(1)
		else:
			mapped.append(0)

	return mapped
# -----------------------------------------------------------------------
def plotData(mapped):
	"""
	Display map of data usage in the buffer, "*" data used and "_" not used
	"""
	col=0
	for idx in range(len(mapped)):
		if idx == 0:		# first address special case
			print("0x%0.4X"%idx, end=' ', flush=True)

		if mapped[idx] == 1:
			print("*", end=' ', flush=True)
		else:
			print("_", end=' ', flush=True)
		col+=1
		if col == 32:
			if (idx*128+128) < 65535:
				print("")
				print("0x%0.4X"%int(idx*128+128),end=' ', flush=True)
				col=0
	return
# -----------------------------------------------------------------------
def packetData(mapped):
	data=[]
	"""
	create a list of tuples [(start_address,size),(start_address,size),...,(start_address,size)] ... size can be 128,256,384,512
	in other words find continues ranges of 128Byte data that has changed, group into packets of 128-512 bytes, create a list for later processing
	"""
	n=0
	col=0
	start=-2
	for idx in range(len(mapped)):
		if mapped[idx] == 1:
			if n == 0:
				start = idx*128
			n+=1
			if n == 4:
				data.append((start,512))
				n=0
		else:
			if n > 0:
				start = (idx-n)*128
				data.append((start,n*128))
			n=0
			start = -2		
	return data
# -----------------------------------------------------------------------
def Decode(len, sum, addr, data):

	"""
	Borrowed this from www.sbprojects.net, credits to San Bergmans

	Decode an Intel string.

	Returns a list of N bytes.
	Returns an empty list if an error has occurred.
	"""

	global Errors

	checksum = len + (addr & 0xFF) + (addr >> 8)
	index = 0
	bytes = []

	if len <= 0 or len > 32:
		# Illegal length
		Eprint("Illegal line length found.")
		Errors += 1
		return bytes

	while len > 0:
		# Iterate over all data bytes
		decimal = int(data[index:index+2], 16)
		bytes.append(decimal)
		checksum = checksum + decimal
		index += 2
		len -= 1

	checksum = (checksum + int(sum, 16)) & 0xFF

	if checksum != 0:
		# Checksum didn't add up
		Eprint("Checksum error.")
		bytes = []
		Errors += 1
		return bytes

	return bytes
# -----------------------------------------------------------------------
def ParseIntelLine(line):

	"""
	Borrowed this from www.sbprojects.net, credits to San Bergmans

	Parse an IntelHex line.
	Record types 02, 03, 04 and 05 are ignored.
	Maximum payload length is 32 bytes.
	Everything after the checksum is ignored.

	Returns True if EOF record found, or when an error is found.
	"""

	global Errors

	# Remove EOL character and leading and trailing white space
	line = line.strip()

	if len(line) == 0:
		# Ignore empty lines
		return False

	# Pad the line with plenty of spaces to make parsing easier
	# We don't have to worry about the line being too short
	line = line + ' '*74

	if line[0] in ('#', ';'):
		# Ignore lines starting with a comment symbol
		return False

	if line[0] != ":":
		# Line must begin with a colon
		Eprint("Illegal start of formatted line.")
		Errors += 1
		return True

	if line[7:9] in ('02', '03', '04', '05'):
		# These record types are simply ignored
		return False

	if line[0:11] == ":00000001FF":
		# End of file marker found
		return True

	datalength = int(line[1:3], 16)
	checksum_index = (datalength + 4) * 2 + 1
	checksum = line[checksum_index:checksum_index + 2]
	address = int(line[3:7], 16)
	data = line[9:checksum_index]

	# Decode the dataline
	bytes = Decode(datalength, checksum, address, data)
	if len(bytes) == 0:
		# Decoding the line resulted in an error
		return True

	#print(address, bytes)
	for x in range (0,len(bytes)):
		buff64k[x+address] = bytes[x]
# -----------------------------------------------------------------------

# sg.theme('DarkAmber')   # Add a touch of color



# form = sg.FlexForm('Eprom emulator Uploader 2.0')
# from serial.tools.list_ports import comports
# com = [p.device for p in comports()]
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

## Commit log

2024-03-06 Initial Commit
    Add existing files to the repo to manage with Git
    [HEC1.kicad_pcb, HEC1.kicad_sch, HEC_CPU.kicad_sch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]
2024-03-07 Update NMI timing circuit
    Updated the NMI generation circuit to prevent a bug occurring when NMI is generated between the rising edge of the last T cycle of an instruction and the falling edge of M1 of the next. Due to delay in M1 signal, the NMI would be qualified one instruction earlier, causing the HEC to enter SYS mode one instruction earlier. If the instruction is an IO instruction by an user program, it can cause a write to any port and potentially destabilize the system.
    [HEC1.kicad_sch, HEC_CPU.kicad_sch, HEC_Protection.kicad_sch]
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2024-03-07 Add NMI reset circuit
    Added a circuit that will reset /NMI state for the HEC and allow further NMI when /INTEN or /GOUSR port is accessed.
    [HEC_Protection.kicad_sch]
2024-03-14 Update to protection circuit
    Update the protection circuit to prevent all interrupts when HEC is in SYS mode
    [HEC_Protection.kicad_sch]
2024-03-15 Add fault generation circuit
    Add circuit to generate fault on illegal read, write and M1 cycle
    [HEC_CPU.kicad_sch, HEC_Protection.kicad_sch]
2024-03-15 Complete fault generation circuit
    Add circuit to generate fault on illegal IO access. The protection circuit design is not considered complete.
    [HEC_CPU.kicad_sch, HEC_Protection.kicad_sch]
2024-03-19 Add HEC Bus
    The HEC bus packs a lot of information into a small amount of pins. It is suitable for cards with various complexity.
    [HEC1.kicad_pcb, HEC1.kicad_sch, HEC_CPU.kicad_sch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]
2024-03-19 Created footprint for HEC bus
    Created footprints for HEC bus and some other updates.
    [HEC1.kicad_pcb, HEC1.kicad_sch, HEC_CPU.kicad_sch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]
2024-03-19 IO implementation
    Implemented most of IO functions, add connections between the schematics.
    [HEC1.kicad_sch, HEC_CPU.kicad_sch, HEC_IO.kicad_sch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]
2024-03-19 Add wait state generator
    Add circuit to generate 0 to 15 wait states or use external wait input.
    [HEC1.kicad_sch, HEC_CPU.kicad_sch, HEC_IO.kicad_sch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]
2024-03-19 Saved changes for added save state generator
    Some changes for the wait state generator was not saved in the last commit
    [HEC_IO.kicad_sch, HEC_Memory.kicad_sch]
2024-03-20 MATX-compliant motherboard
    Made the motherboard mounting holes and card positions MATX compliant. The MATX motherboard edge is shifted 0.5 inches to the left, which is annoying. Also, cards have component on the opposite side 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
    [HEC1.kicad_pcb, HEC1.kicad_sch, HEC_CPU.kicad_sch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]
2024-03-20 PCB Update
    Some part placement, some routing, some change in schematic for easier PCB routing.
    [HEC1.kicad_pcb, HEC1.kicad_sch, HEC_CPU.kicad_sch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]
2024-03-20 Add POST code circuit
    Add circuit to show POST code using I register on Z80 to assist debugging.
    [HEC1.kicad_pcb, HEC_CPU.kicad_sch, HEC_IO.kicad_sch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]
2024-03-21 Cleanup schematic
    Cleanup the schematic for easier reading, reduce ERC errors.
    [HEC1.kicad_sch, HEC_CPU.kicad_sch, HEC_IO.kicad_sch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]
2024-03-21 Add keyboard circuit
    Added symbol for HT6542B keyboard controller. Added keyboard and mouse support to IO circuit. Reduced ERC error to 0.
    [HEC1.kicad_sch, HEC_IO.kicad_sch, HEC_Protection.kicad_sch]
2024-03-24 Split peripherals into separate schematic
    Split graphics/sound/storage (VERA) board connector and keyboard/mouse controller into a separate schematic file. Add joystick/controller port. This commit is seriously delayed by the controller port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
    [HEC1.kicad_sch, HEC_CPU.kicad_sch, HEC_IO.kicad_sch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]
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2024-04-02 Removed DMA from bus
    Bus-mastering DMA has been removed from the expansion bus design due to complexity and bandwidth issue with external bus expansion circuit. The pins are replaced with audio output from on-bard sound system. Minor changes to pin names.
    [HEC1.kicad_sch, HEC_CPU.kicad_sch, HEC_IO.kicad_sch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]
2024-04-02 Add Mini-DIN-6 footprint
    It turns out that KiCad had only symbol but not footprint for Mini-DIN-6. Therefore I used a custom one made by 4x1md
    [HEC1.kicad_sch, HEC_IO.kicad_sch, HEC_Peripherals.kicad_sch]
2024-04-05 PCB Layout attempt
    Played with PCB layout a bit to get an idea of how the layout of HEC would look like. Minor updates to schematic to simplify PCB layout.
    [HEC1.kicad_pcb, HEC_CPU.kicad_sch, HEC_Peripherals.kicad_sch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]
2024-04-08 double Mini DIN 6 port
    Added double Mini DIN 6 port to replace two Mini DIN 6 port to save cost and simplify building process. The footprint is derived from the existing single mini DIN 6 port. With changes according to the png schematic. This is my first attempt at creating a footprint beyond simple 0.1inch pads, so it may be wrong. Minor changes to the PCB.
    [HEC1.kicad_pcb, HEC_Peripherals.kicad_sch, HEC_Protection.kicad_sch]
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2024-04-08 Updated layout
    Updated the layout of PCB. Chips on the board in this version might be in their final position.
    [HEC1.kicad_pcb, HEC1.kicad_sch, HEC_CPU.kicad_sch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]
2024-04-08 New bus symbol
    Updated bus symbol and footprint to simplify PCB layout.
    [HEC1.kicad_pcb, HEC_IO.kicad_sch, HEC_Protection.kicad_sch]
2024-04-09 Exchange RI and NX pins on bus driver
    A mistake is found in the schematic: the RI and NX bits are exchanged on the 74245 bus driver chip. The mistake has been corrected. This change is significant since it changes the (non-existent) software programming model. More playing around with the layout.
    [HEC1.kicad_pcb, HEC_CPU.kicad_sch, HEC_IO.kicad_sch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]
2024-04-09 Add prototyping region
    Add some prototyping regions to the board, since there WILL be bugs!
    [HEC1.kicad_pcb, HEC_CPU.kicad_sch, HEC_Memory.kicad_sch]
2024-04-11 Some routing attempt
    Attempted to route some traces. 2-layer PCB seems to be achievable. It might just be a fool's arrogance.
    [HEC1.kicad_pcb]
2024-04-13 More routing
    Swapped U15 and U16, minor adjustments to schematic. routing of power lines.
    [HEC1.kicad_pcb, HEC_CPU.kicad_sch, HEC_Memory.kicad_sch]
2024-04-13 Update to bus pinout
    Move /RD and /WR signal closer to /CS to simplify add-on card design for common chips. From a simple search of pinouts of common chips this may reduce the amount of vias needed on the card.
    [HEC_IO.kicad_sch]
2024-04-14 More routing
    Finished routing the IO part of the board. Currently it doesn't seem like a 4-layer board is needed.
    [HEC1.kicad_pcb, HEC_Peripherals.kicad_sch]
2024-04-14 Livestream routing
    First routing livestream! Routed a data bus and some traces protection and memory region.
    [HEC1.kicad_pcb, HEC_Protection.kicad_sch]
2024-04-14 Bug fixes
    fixed some bugs introduced to the schematic. More routing.
    [HEC1.kicad_pcb, HEC1.kicad_sch, HEC_IO.kicad_sch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]
2024-04-14 More routing, a power LED
    Did some easier routing. The current concern is that the already done easy routing would take up space for harder to route traces, making them even harder. However, one have to start somewhere... The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
    [HEC1.kicad_pcb, HEC1.kicad_sch, HEC_IO.kicad_sch]
2024-04-15 More routing
    Even more routing... Maybe 50% finished? The remaining 50% is probably harder though.
    [HEC1.kicad_pcb, HEC_Memory.kicad_sch]
2024-04-15 Livestream commit
    Committing live! Just to make sure that I don't lose 1 day of work.
    [HEC1.kicad_pcb, HEC1.kicad_sch, HEC_Memory.kicad_sch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]
2024-04-15 End of livestream
    State of the project at the end of the livestream, still not finished.
    [HEC1.kicad_pcb]
2024-04-15 Bottom left routing complete
    Finished routing the bottom left side of the PCB (wait generation and part of protection). Minor changes to schematic to ease routing.
    [HEC1.kicad_pcb, HEC_Memory.kicad_sch]
2024-04-15 More routing
    Routing starts to become harder since most of the board is occupied. I should REALLY use a set of constraints that allow me to route two traces between adjacent pads...
    [HEC1.kicad_pcb]
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2024-04-16 fix DRC errors, generate gerbers
    Fixed all DRC errors (except a few silkscreen clipped warnings). Generated gerber files for first version of the board.
    [HEC1-B_Cu.gbr, HEC1-B_Mask.gbr, HEC1-B_Paste.gbr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]
2024-04-25 Correct gerber files
    [HEC1-NPTH-drl.gbr, HEC1-PTH-drl.gbr, HEC1-PTH-edit-drl.gbr]
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2024-04-26 Fixes to 2 issues found in the first prototype
    Added jumper pads to allow user to switch between 74LS47 and DM9368 7-segment decoder chips, add reset timing capacitor.
    [HEC1.kicad_pcb, HEC_CPU.kicad_sch]
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2024-06-09 change NX bit to XE bit
    change No eXecute to eXecute Enable (inverting the polarity of the signal) in order to fix a bug that causes the HEC to not recognize a NX when the instruction fetched is a RST.
    [HEC1.kicad_sch, HEC_CPU.kicad_sch, HEC_Memory.kicad_sch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]
2024-06-13 Fixed reversed POST code display
    Wrote a program to test the POST code LED display, found out it's backwards, and fixed it in schematic
    [HEC_CPU.kicad_sch]
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2024-06-21 Fancy power circuit
    Added a circuit to switch power, short press to power on, long press to power off.
    [HEC1.kicad_sch, HEC_Protection.kicad_sch]
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2024-07-05 Remove external ROM emulator connector
    Removed the connector for connecting to ROM emulator. The connector was not a particular success as a 34-pin ribbon cable instead of 28 pin is required. The absence of a reset pin was also a mistake. Next generation of HEC will move towards probe-based prototyping or in-situ flashing. Removed R1 and C36 as their role is duplicated.
    [HEC_CPU.kicad_sch]
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
